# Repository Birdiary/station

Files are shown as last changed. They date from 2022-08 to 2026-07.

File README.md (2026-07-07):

# Birdiary - station
Nowadays, more species are threatened with extinction than ever before in the human era.
Especially breeding birds are considered endangered. 
At the same time, it is difficult to obtain sufficient data not only to raise awareness for this situation, but also to gain a better understanding and to develop potential countermeasures.
The Birdiary project demonstrates how a citizen science based biodiversity monitoring for birds, using an automated and easy-to-use multi-sensor feeder, can look like. 
A smart bird feeder including an environmental sensor, a microphone, as well as a balance and a camera in a wooden case which identifies the type of visiting birds using AI and publishes the recognized species, including all further collected data on an open access website. 
The station can be reproduced by anyone at an affordable price in a Do-It-Yourself format, making citizens a key contributor to biodiversity monitoring.

This repository contains the code to run the bird feeder which is equipped among other things with a camera, balance, microphone and further environmental sensors. 
All the collected data is sent to a server which is based on this [webserver](https://github.com/Birdiary/webserver). 
The repositories are currently still under development, the code for the operation of the feeder as well as for the web server are continuously updated. 
A corresponding manual for the operation of the system including open source instructions for building the feeder is available online: [Birdiary Manual](https://docs.google.com/document/d/1ItowLull5JF3irzGtbR-fCmgelG3B7DSaU1prOeQXA4/). 

Birdiary is a project which was launched by a group of students at the Institute for Geoinformatics at the University of Münster. 
If you got any questions contact us via: [info@wiediversistmeingarten.org](mailto:info@wiediversistmeingarten.org).

Any further information you can find via: [birdiary.de](https://www.wiediversistmeingarten.org/). 

## Advanced Software Development by the Community 
Citzien Scientists are driving the project substantially forward, leading to a large number of further developments. This also includes modifications to the code base. 
Some of these modifications are added directly here in the code (see [How to Contribute]([https://github.com/Birdiary/station?tab=readme-ov-file#suggest-feature](https://github.com/Birdiary/station?tab=readme-ov-file#how-to-contribute))), but some are also hosted in separate repositories. 
In the following, we list these developments. We would like to inform you that no guarantee or liability is assumed for their functionality and ask you to contact the respective operators of the repositories directly if you have any questions.  

* [Birdiary Image Raspberry Pi Zero 2 W](https://osf.io/w8gef): The available PDF describes the necessary adjustments needed to enable the Birdiary image to be used on a Raspberry Pi Zero 2 W. 
* [betzBirdiary](https://github.com/herbbetz/betzBirdiary): Modified code base that may be of interest to those using the Raspberry Pi Zero 2 W or Raspberry Pi 4 Model B as microcontroller. The repository uses the libraries Picamera2 and Pigpio (for DHT and HX711), is compatible with Bookworm (Raspian Debian 12) and includes a GUI for configuration purposes. 
* [Birdiary on ESP32](https://github.com/tnier01/BirdiaryStationESP32/): The repository details how to run a Birdiary station using ESP32, especially Seeed Studio XIAO ESP32S3 Sense.
* [Duisbird](https://duisbird.de/) Members of the Makerspace at VHS Duisburg developed their own version of the station based on ESP32S3 which is advanced compared to the other implementations, optimizing several aspects. You can find the information on the respective website: [https://duisbird.de/](https://duisbird.de/).

## How to Contribute
Thank you for considering contributing to Birdiary. Birdiary is an open source project, and we love to receive contributions from our community — you!
There are many ways to contribute, from writing tutorials or blog posts, improving the design of the station, submitting bug reports and feature requests or writing code which can be incorporated into Birdiary itself.
We use GitHub to host code, to track issues and feature requests, as well as accept pull requests.
This Repository comprises the code and issues for the station. Which means, if you want to contribute to the code running on the station, please contribute here. *Contributions in this repository do not have to stick to the code. They can also be about the hardware or design of the station.* Whereas when you want to contribute to the webserver (website), please use this repository [Webserver](https://github.com/Birdiary/webserver).

### Reporting Bugs
If you find a security vulnerability, do NOT open an issue. Email info@wiediversistmeingarten.org instead.
 
If you encounter a bug, check if the bug has already been reported as [issue](https://github.com/Birdiary/station/issues). If the bug has not been reported, you can open a [new issue](https://github.com/Birdiary/station/issues/new) to report the bug, please add the label "bug".
 
When filing an issue, make sure to answer these four questions:
> 1. Which hardware components (e.g. microcontroller, sensors) are you using?
> 2. Which software components (e.g. IDE, libraries, packages) are you using?
> 3. What did you do?
> 4. What did you expect to see?
> 5. What did you see instead?

### Suggest Feature
If you wish a special feature, feel free to add it as new [issue](https://github.com/Birdiary/station/issues/new). Here, please add the label "enhancement". We appreciate any suggestions.

### Code Contributions
Besides reporting bugs or suggesting features, we really appreciate code contributions. We suggest contributing through forking and pull-requests. A guideline how to fork a project and create a pull request can be found in the [Contribution to Projects Guidelines](https://docs.github.com/en/get-started/quickstart/contributing-to-projects). 
 
We review pull requests on a regular basis and give feedback or merge them directly into our main repository.

### Validating an Issue and Pull Requests
You can also contribute by merging a pull request into your local copy of the project and testing the changes. Add the outcome of your testing in a comment on the pull request.
Further, you can validate an issue or add additional context to an existing issue.

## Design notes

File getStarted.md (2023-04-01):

# Vorbereitung Pi 
- Installiere den Raspberry Pi Imager auf deinem lokalen Computer (Den Imager findest du hier: https://www.raspberrypi.com/software/)
- Verbinde die SD Karte, die später einmal im Raspberry Pi genutzt wird, mit deinem Computer (in der Regel kannst du die Micro SD Karte mit einem beigelegten Adapter in deinen PC stecken)
  - Da alle Daten auf der SD Karte gelöscht werden, solltest du eventuelle Daten vor den folgenden Schritten abgespeichert haben 
  - Starte den Raspberry Pi Imager und wähle dann im User Interface "Raspberry PI OS (32-BIT)" als Betriebssystem aus 
    - Wähle im User Interface des Raspberry Pi Imager, die SD Karte aus, die du eben mit deinem Computer verbunden hast 
    - Um den Prozess, der Betriebssystemübertragung zu beginnen, wähle entsprechend "SCHREIBEN" aus 
    - Bestätige, dass alle Daten auf der SD Karte gelöscht werden können 
  - Sobald die Bestätigung angezeigt wird, dass "Raspberry Pi OS (32-bit)" auf der eingelegten SD Karte gespeichert wurde, kann diese vom Computer entfernt werden und in den Raspberry Pi eingelegt werden (der Slot dafür ist auf der Unterseite des RaspberryPi, gegenüber der USB-Anschlüsse)
    - Solange das Überspielen auf die SD-Karte läuft, können schon die nächsten Schritte bis zum Stromanschluss durchgeführt werden  
- Nutze zwei der vier USB Ports am Raspberry Pi um sowohl Tastatur, als auch eine Maus an den Raspberry Pi anzuschließen 
- Nutze den Mini-HDMI Port mit der Aufschrift "HDMI0" um einen Bildschrim mit dem Raspberry Pi zu verbinden
- Optional wäre über "HDMI1" ein weiter Bildschirm verbindbar 
- Schließe das RaspberryPi Netzteil an der Buchse mit der Bezeichnung "POWER IN" an, um den Raspberry Pi mit dem Strom zu verbinden 
- Sofern dein Bildschirm eingeschaltet ist, sollte der Raspberry Pi nun starten und eine graphische Nutzerberfläche angezeigt werden, dies kann ein paar Minuten dauern. 

# initiales Starten Raspberry Pi  
- Es kann sein, dass es zu der Meldung kommt "Resized root file system. Rebooting in 5 seconds". Dann einfach abwarten und der Raspberry Pi startet selbständig erneut 
- Erscheint die Oberfläche, gilt es noch einige Einstellungen durchzuführen 
  - Zunächst können Land, Sprache und Zeitzone eingestellt werden 
  - Anschließend können Nutzername und Passwort spezifiziert werden (in der Regel 
  - Anschließend kann die Bildschirmgröße angepasst werden 
  - Dann ist es möglich, dass WiFi Network festzulegen, dies am besten gleich tun 
- Anschließend kann optional das Betriebssystem aktualisiert werden 
- Mit einem Neustart wird der Raspberry Pi dann nutzbar  

# initiales Setup Raspberry Pi 
Für die folgenden Schritte öffnest du am einfachsten dieses Repository in dem Browser (Globus Icon, oben links neben der Himbeere) deines Raspberry Pi, um die Kommandos zu kopieren. 

Zur Info: Eingaben im Terminal können getätigt werden, wenn die (grüne) Zeile `pi@raspberry: ~ $` erscheint. Dies ist auch das Zeichen für eine abgeschlossene Eingabe / Installation.

## Kamera 
- Öffne das Terminal (Shortcut: Strg + Alt + T)
- Eingabe im Terminal: `sudo raspi-config`
  - Navigation mit Pfeiltasten
  - Auswahl von: 3 Interface Options  
  - Auswahl von: I1 Legacy Camera
  - Auswahl von: Ja
  - Auswahl von: Finish  
  - Auswahl von: Ja (Reboot)

## Installation verschiedener Pakete 
- Eingabe im Terminal: `pip3 install pyyaml` (Definition der Parameter)
- Eingabe im Terminal: `pip3 install schedule` (zeitliche Wiederholung der Umweltdaten Sendung)
- Eingabe im Terminal: `pip3 install --upgrade numpy`

## Luftfeuchte und Temperatur Sensor 
- Eingabe im Terminal: `sudo pip3 install adafruit-circuitpython-dht`
- Eingabe im Terminal: `sudo apt-get install libgpiod2`

## Mikrofon 
- Eingabe im Terminal: `sudo pip3 install --upgrade adafruit-python-shell`
- Eingabe im Terminal: `wget https://raw.githubusercontent.com/adafruit/Raspberry-Pi-Installer-Scripts/master/i2smic.py`
- Eingabe im Terminal: `sudo python3 i2smic.py`
  - Bestätige 'Load on reboot' mit `y` -> Enter
- Für die vorherigen drei Schritte ist eine detaillierte Anleitung unter folgendem Link zu finden: https://learn.adafruit.com/adafruit-i2s-mems-microphone-breakout/raspberry-pi-wiring-test 
- Eingabe im Terminal: `sudo apt-get install libatlas-base-dev libportaudio2 libasound-dev`
- Eingabe im Terminal: `python3 -m pip install --user sounddevice`
  - Gegebenenfalls im Terminal bestätigen durch die Eingabe von `j` und Enter. 
- Eingabe im Terminal: `python3 -m pip install --user scipy`
- Für die vorherigen drei Schritte ist eine detaillierte Anleitung unter folgendem Link zu finden: https://github.com/Infineon/i2s-microphone/wiki/Raspberry-Pi-Audio-Processing-with-Python 
- Eingabe im Terminal: `pip3 install SoundFile`

# Hardware anschließen 

Die Belegung und Nummerierung der Pins / Ports des Raspberry Pi kann unter anderem hier nachgeguckt werden: https://www.raspberrypi-spy.co.uk/wp-content/uploads/2012/06/Raspberry-Pi-GPIO-Header-with-Photo.png 

## Kamera 
- Das breite weiße Kamerakabel an einem Ende an die Kamera anschließen und am anderen Ende an den RasperryPi (an den Anschluss der mit Kamera betitelt ist), so, dass das blaue Ende zu den USB Anschlüssen zeigt 
- Das Kabel lässt sich sowohl an Pi als auch an Kamera durch das hochziehen, der grauen Abdeckung befestigen. Dieses anschließend wieder runterdrücken um das Kabel zu fixieren 

## Luftfeuchte und Temperatursensor 
- "+" -> Port 1 (3,3 V)
- Out -> Port 36 (GPIO 16)
- "-" -> Port 9 (GND) 

## Waage 
- Kabel von der Waage (Dehnungsmessstreifen) zur Wägezelle:
  - Rot: E+ 
  - Schwarz: E-
  - Grün: A-
  - Weiß: A+
- Kabel vom Pi zur Wägezelle:
  - VCC -> Port 2 (5 V)  
  - SCK -> Port 16 (GPIO 23) 
  - DT  -> Port 11 (GPIO 17)
  - GND -> Port 6 (GND)

## Mikrofon 
- SEL -> Port 39 (GND)
- RCL -> Port 35 (GPIO 19)
- OUT -> Port 38 (GPIO 20)
- CLK -> Port 12 (GPIO 18) 
- GND -> Port 20 (GND)
- 3V  -> Port 17 (3,3 V)

# Setup Birdiary
(Je nachdem mit welchen Benutzer man sich am RaspberryPi anmeldet, können die Verzeichnisse abweichen. Solltest du dich nicht mit dem Benutzer 'pi' anmelden, musst du den Verzeichnisnamen gegen Deinen austauschen. Aus /home/pi wird dann /home/<dein Benutzer>)
- Eingabe im Terminal: `cd /home/pi/`
- Eingabe im Terminal: `git clone https://github.com/CountYourBirds/station.git` 
- Erstelle unter https://wiediversistmeingarten.org/react/createbox deine eigene Station
- Kopiere die Box-Id in die config.yaml-Datei im Ordner `/home/pi/station`
- Navigiere in den Ordner station und öffne die `config.yaml`-Datei mit geany (Rechtsclick auf die Datei -> Geany)
  - Kopiere die Box-id an die entsprechende Stelle in der Datei
  - Speichere die Datei (Shortcut: Str + S)

# Ermöglichung des Zugriffs auf den Raspberry Pi via VNC  
- Eingabe im Terminal: `sudo nano /boot/config.txt` (detaillierte Anleitung für die Veränderung der Datei hier: https://www.shellhacks.com/raspberry-pi-force-hdmi-hotplug/)
  - Navigiere mit den Pfeiltasten der Tastatur zu den den folgenden Zeilen, entferne die Rauten am Anfang der Zeilen und nimm die entsprechenden Anpassungen vor:
    - Setze den Paramter hdmi_force_hotplug auf 1: `hdmi_force_hotplug=1`  
    - Setze den Parameter hdmi_group auf 1: `hdmi_group=1`
    - Setze den Parameter hdmi_mode auf 16: `hdmi_mode=16`
  - Zum Speichern: 
    - `Strg`+ `O` 
    - `Enter`
    - `Strg`+ `X` 
- Eingabe im Terminal: `sudo raspi-config`
  - Auswahl von: 2 Display Options
  - Auswahl von: D5 VNC Resolution  
  - Auswahl von: 1920x1080
  - Auswahl von: OK
  - Auswahl von: 3 Interface Options 
  - Auswahl von: VNC 
  - Auswahl von: Ja 
  - Auswahl von: Finish
  - Auswahl von: Ja (Reboot)
- Kurz abwarten und das `Va` Icon anklicken oben rechts neben dem WLAN Zeichen 
- IP Adresse die unter Konnektivität gelistet ist auf Rechner der auf PI zugreifen soll im VNC Viewer eintragen (vorheriger Download der VNC Viewer App für entsprechendes Betriebssystem: https://www.realvnc.com/de/connect/download/viewer/) und mit dem Raspberry Pi verbinden  
- Passwort und Benutzername des pis entsprechend eintragen
- Verbindung sollte funktioneren  

# Automatische Ausführung ermöglichen 
- Eingabe im Terminal: `sudo apt-get install xterm`
  - Bestätigung mit `J` -> Enter  
- Eingabe im Terminal: `mkdir -p ~/.config/autostart`
  - (Das Terminal gibt kein Feedback bei erfolgreicher Ausführung, außer, dass eine neue Zeile und keine Fehlermeldung erscheinen)  
- Eingabe im Terminal: `nano ~/.config/autostart/lxterm-autostart.desktop`
- In der Datei einfügen: 
```
[Desktop Entry]
Encoding=UTF-8
Name=Terminal autostart
Comment=Start a terminal and list directory
Exec=/usr/bin/lxterm -e 'bash ~/station/startup.sh'
```
- `Strg`+ `O` 
- `Enter`
- Eingabe im Terminal: `sudo reboot`

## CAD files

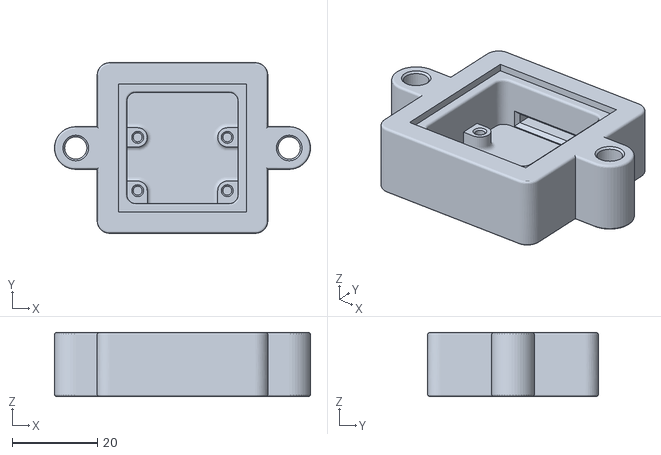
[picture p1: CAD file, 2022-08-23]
files/Cam_Support.stl
60.0 x 40.0 x 15.0

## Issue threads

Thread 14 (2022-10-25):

sensors and cables at bottom are unprotected and loose

jsten07, 2022-10-25:
Microphone and temperature / humidity sensor are hanging loose at the bottom of the station.

- Create protection with wood or 3D-printer
- At least mount sensors with screws to bottom

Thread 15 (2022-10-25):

difficult to mount station at a wall with the peaked roof

jsten07, 2022-10-25:
Peaked roof has some overhang at the back so it can not be mounted to a wall easily

- Shorten roof at the back
- Build station with pitched roof

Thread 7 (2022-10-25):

Power supply (cable) unprotected

jsten07, 2022-10-25:
Just the usual Raspberry Pi power supply is plugged into the USB-C port, so it is exposed to the elements and difficult to fasten.

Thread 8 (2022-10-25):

Enlarge room for fodder

jsten07, 2022-10-25:
Partially solved by mounting the interior wall angled

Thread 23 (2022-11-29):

"out of resources" while starting the camera

NJaku01, 2022-11-29:
With the new program I had the problem that there always was the problem "out of resources" when it tried to start the camera, since it also was sending all movements at the same time. After removing all movements to send, it worked properly again. So my solution would be not start the camera and send the data at the same time

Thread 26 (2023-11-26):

Exchange DHT22

Marwe, 2023-11-26:
We had bad experiences with the DHT22 sensor in measurement stations (values, productive life time), BME280 is our current recommended sensor (see https://sensor.community/de/sensors/airrohr/).

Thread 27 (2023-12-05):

weatherproof and stand-alone station

tnier01, 2023-12-05:
The weather protection of the station should be reconsidered. If it is not treated with linseed oil or varnish, mould can easily form.
Perhaps there are other treatment options for the wood, or other materials such as 3D printing, which would make the station more robust. Otherwise, there will be many negative experiences, which will increasingly reduce the motivation of the citizen scientists involved.

- [ ] Strengthening the weather resistance of the station

In addition, the station should be designed to operate autonomously. This includes various aspects, such as the power connection (cable, PowerBank, solar) but also the network connection (Wifi, mobile radio, LoRa)

- [ ] stand-alone station

This issue serves as a starting point for the discussion and should result in many individual aspects and issues.

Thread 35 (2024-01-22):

Assistant who guides you through the initial installation

tnier01, 2024-01-22:
There should be a wizard that guides you through the initial installation process as soon as the SD card is inserted in the Raspberry Pi. This can include the following steps:
- Setting up config.yaml (boxId, environmentTimeDeltaInMinutes, weightThreshold, calibration_weight, terminal_weight, cameraRotation, weightResetInMinutes)
- All required files downloaded
- Performed all required adjustments to the operating system.

Similar to MrBeam, it should be possible to establish a connection to the Raspberry Pi via a local network hosted by the Raspberry Pi using a website that guides you through the installation process.

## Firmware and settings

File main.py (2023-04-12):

import sys
import shutil
import time
import schedule
import numpy as np
from datetime import datetime, timedelta 
import os 
import yaml
import json
import logging
from logging.handlers import TimedRotatingFileHandler
import glob
import requests



dev_mode = False
if not dev_mode:
    import requests

if not os.path.exists('files'):
    os.makedirs('files')
if not os.path.exists('logs'):
    os.makedirs('logs')
if not os.path.exists('environments'):
    os.makedirs('environments')
if not os.path.exists('movements'):
    os.makedirs('movements')
else: 
    files = glob.glob('movements/*')
    for f in files:
        os.remove(f)
if not os.path.exists('savedMovements'):
    os.makedirs('savedMovements')
if not os.path.exists('temp'):
    os.makedirs('temp')

logname = "logs/birdiary.log"
file_handler = TimedRotatingFileHandler(logname, when="midnight", interval=1)
file_handler.suffix = "%Y%m%d"

""" # This block just works for Python version >= 3.9
logging.basicConfig(encoding='utf-8', 
                    level=logging.DEBUG, 
                    format='%(asctime)s %(levelname)s: %(message)s',
                    handlers=[
                      file_handler,
                      logging.StreamHandler(sys.stdout)
                    ]
) 
"""
logger = logging.getLogger()

logger.setLevel(logging.DEBUG)  
logger.addHandler(file_handler)
logger.addHandler(logging.StreamHandler(sys.stdout))


logging.info("Start setup!") 

# Read config.yaml file
logging.info("Reading configuration file!")
with open("config.yaml", 'r') as stream:
    yamlData = yaml.safe_load(stream)
    
# parse loglevel if present
try:  # make it backward compatible to older Versions
    loglevel = yamlData["misc"]["loglevel"]
    if loglevel == 0 or loglevel == 10 or loglevel == 20 or loglevel == 30 or loglevel == 40 or loglevel == 50:
        # referring to https://docs.python.org/3/library/logging.html#logging-levels
        logger.setLevel(loglevel)
    else:
        logger.error("Loglevel in configuration file wrong")
except:
    logger.error("loglevel in configuration not set")

# parse dev_mode if present
try:  # make it backward compatible to older Versions
    dev_mode = yamlData["misc"]["dev_mode"]
except:
    dev_mode = False
    logger.error("dev_mode in configuration not set, disabled by default")

serverUrl = yamlData["server"]["url"]
boxId = yamlData["station"]["boxId"]
environmentTimeDeltaInMinutes = yamlData["station"]["environmentTimeDeltaInMinutes"] # waiting time to send environment requests 
weightThreshold = yamlData["station"]["weightThreshold"] # weight which is the threshold to recognize a movement 
terminal_weight = yamlData["station"]["terminal_weight"] # reference unit for the balance
calibration_weight = yamlData["station"]["calibration_weight"] # reference unit for the balance
camera_rotation =  yamlData["station"]["cameraRotation"]
weightResetInMinutes = yamlData["station"]["weightResetInMinutes"]

logging.info('loglevel=' + str(loglevel))
logging.info('dev_mode=' + str(dev_mode))
logging.info('environmentTimeDeltaInMinutes=' + str(environmentTimeDeltaInMinutes))

# Setup Camera 
logging.info("Setup camera!")
import io
import random
import picamera

camera = picamera.PiCamera()
camera.rotation = camera_rotation
camera.resolution = (1280, 960)
stream = picamera.PiCameraCircularIO(camera, seconds=5)
camera.start_recording(stream, format='h264')

# Setup DHT22 (humidity + temperature) 
logging.info("Setup DHT22!")
import adafruit_dht
from board import *
SENSOR_PIN = D16 # use not board but GPIO number 
dht22 = adafruit_dht.DHT22(SENSOR_PIN, use_pulseio=False)

# Setup Balance
logging.info("Setup balance!")
EMULATE_HX711=False

if not EMULATE_HX711:
    import RPi.GPIO as GPIO
    from balance.hx711 import HX711
else:
    from balance.emulated_hx711 import HX711

hx = HX711(17, 23)

hx.set_reading_format("MSB", "MSB")
# readValueTerminal/referenceValueOnBalance=referenceUnit e.g. -1020389.3333333334/1000 = -1020,389

if calibration_weight != 0:
    balanceReferenceUnit = terminal_weight/calibration_weight
    hx.set_reference_unit(balanceReferenceUnit)

hx.power_up()
hx.reset()
time.sleep(30)
hx.tare()

# Setup Microphone 
logging.info("Setup microphone!")
from rec_unlimited import record
from multiprocessing import Process

logging.info("Setup finished!") 
 
def write_environment(environment_data):
    filename = 'environments/' + environment_data['date'] + '.json'
    with open(filename, 'w') as wfile:
        json.dump(environment_data, wfile)

def write_movement(movement_data):
    with open(data_filename, 'w') as jsonfile:
        jsonfile.write(movement_data)

# Function to send movement data to the server
def send_realtime_movement(files):
        
    if dev_mode:
        logging.warning('send_movement deactivated')
        logging.warning('received: ' + str(video_filename) + ' ' + str(audio_filename) + ' ' + str(data_filename))
    else:
        try:
            logging.debug(serverUrl + 'movement/' + boxId)
            r = requests.post(serverUrl + 'movement/' + boxId, files=files, timeout=60)
            logging.info('Following movement data send: %s', files)
            logging.debug('Corresponding movement_id: %s', r.content)
        except (requests.ConnectionError, requests.Timeout) as exception:
            logging.warning('No internet connection. ' + str(exception))
            logging.warning('Saving files to send later')
            shutil.move(audio_filename, save_audio_filename)
            shutil.move(video_filename, save_video_filename)
            write_movement(files['json'][1])
        else:
            os.remove(video_filename)
            os.remove(audio_filename)

def send_realtime_environment(environmentData):
    if dev_mode:
        logging.warning('send_environment deactivated')
        logging.warning('received: ' + str(environmentData))
    else:
        try:
            r = requests.post(serverUrl + 'environment/' + boxId, json=environmentData, timeout=20)
            logging.info('Following environment data send: %s', environmentData)
            logging.debug('Corresponding environment_id: %s', r.content)
        except (requests.ConnectionError, requests.Timeout) as exception:
            logging.warning('No internet connection. ' + str(exception))
            logging.warning("Saving environment data to send later")
            write_environment(environmentData)
        else:
            send_data()            

# Function to track a environment  
def track_environment(): 
    try:
      logging.info("Collect Environment Data") 
      environment = {}
      environment["date"] = str(datetime.now())
      environment["temperature"] = dht22.temperature
      environment["humidity"] = dht22.humidity
      
      logging.info("Environment Data: ")
      logging.info(environment)
                  
      send_realtime_environment(environment)
      
      global environmentData 
      environmentData = environment 
    except Exception as e:
      logging.error(e)  

# predefined variables 
environmentData = None
audio_filename = None
video_filename = None
save_audio_filename = None
save_video_filename = None
temp_audio_filename = 'temp/audio.wav'
data_filename = None
recorder = None

def tare():
    weight2 = hx.get_weight(15)
    if(weight2<weightThreshold):
        while((weight2 < -0.5 or weight2>0.5)):
            logging.info("Measured weight:" + str(weight2) + " not in valid range. Start taring")
            hx.tare()
            time.sleep(5)
            weight2 = hx.get_weight(15)
    logging.info("Measured weight:" + str(weight2) + " in valid range. Stop taring")
            



def set_filenames(movementStartDate):
    global save_audio_filename
    save_audio_filename = 'savedMovements/' + str(movementStartDate) + '.wav'
    global save_video_filename
    save_video_filename = 'savedMovements/' + str(movementStartDate) + '.h264'
    global audio_filename
    audio_filename = 'movements/' + str(movementStartDate) + '.wav'
    global video_filename
    video_filename = 'movements/' + str(movementStartDate) + '.h264'
    global data_filename
    data_filename = 'savedMovements/' + str(movementStartDate) + '.json'

# Function to track a movement      
def track_movement(): 
   values = []

   

   
   # schedule an environment track for every x minutes    
   schedule.every(environmentTimeDeltaInMinutes).minutes.do(track_environment)
   schedule.every(weightResetInMinutes).minutes.do(tare)



   while True:
       try:
           schedule.run_pending()
           
           weight = hx.get_weight(15)  
           
           if (weight < weightThreshold  and len(values) == 0):
              logging.info("Waiting for movement! (currently measured weight: " + str(weight) + ")")
           
           # start movement if weight higher than threshold is recognized 
           if (weight > weightThreshold and len(values) == 0):
              logging.info("Movement recognized!") 
              movementStartDate = datetime.now()
              set_filenames(movementStartDate)
              
              global recorder
              recorder = Process(target=record, args=(temp_audio_filename,))
              recorder.start()
              
              camera.wait_recording(1) # continue camera recording 
            
              values.append(weight) # add current weight to weight list 

           else: 
           # continue movement if currently recognized weight is above threshold 
              if (weight > weightThreshold):
                 values.append(weight)
                 camera.wait_recording(1)

                 logging.info("Currently measured weight: " + str(weight))

           hx.reset()          
        
           # stop movement if weight is below threshold 
           if (weight < weightThreshold):
              if (len(values) >= 1):
                 logging.info("Movement ending!") 
                 movementEndDate = datetime.now() 
                 
                 duration = (movementEndDate - movementStartDate).total_seconds()                 
                 stream.copy_to(video_filename, seconds=duration+5)
                 stream.clear()
                                                   
                 movementData = {}
                 files = {}
                 movementData["start_date"] = str(movementStartDate)
                 movementData["end_date"] = str(movementEndDate)
                 movementData["audio"] = "audioKey"
                 movementData["weight"] = np.median(values)
                 movementData["video"] = "videoKey"
                 
                 # stop audio recording and move temporary file to output directory 
                 terminate_recorder()
                 shutil.move(temp_audio_filename, audio_filename)
                 
                 files['audioKey'] = (os.path.basename(audio_filename), open(audio_filename, 'rb'))
                 files['videoKey'] = (os.path.basename(video_filename), open(video_filename, 'rb'))

                 
                 if (environmentData != None):
                    movementData["environment"] = environmentData
                 else: 
                    movementData["environment"] = {}
                 
                 logging.info("Movement Data: ")
                 logging.info(movementData)
                 
                 files["json"] = (None, json.dumps(movementData), 'application/json')

                 send_realtime_movement(files)
                 
                 values = []

                 
       except (KeyboardInterrupt, SystemExit):
           cleanAndExit()
           
def cleanAndExit():
  camera.close()
  terminate_recorder()
  sys.exit(2)
  
def terminate_recorder():
  global recorder
  if recorder is not None and recorder.is_alive():
    recorder.terminate()
    logging.info("terminated recorder")
  else:
    logging.debug("no alive recorder")
    
#Function to send environment data to the server
def send_environment(filename, server_url, box_id):
	try:
		with open(filename, 'r') as envFile:
			data = json.load(envFile)
	except:
		os.remove(filename)
		
	if dev_mode:
		logging.warning('send_environment deactivated')
		logging.warning('received: ' + str(data))
	else:
		try:
			r = requests.post(server_url + 'environment/' + box_id, json=data, timeout=20)
			logging.info('Following environment data send: %s', data)
			logging.debug('Corresponding environment_id: %s', r.content)
		except (requests.ConnectionError, requests.Timeout) as exception:
			logging.warning('No internet connection. ' + str(exception))
		else:
			os.remove(filename)
			
# Function to send movement data to the server
def send_movement(video_filename, audio_filename, data_filename, server_url, box_id):
	try: 
		with open(data_filename, 'r') as dataFile:
			data = json.load(dataFile)
		files = {}
		files['videoKey'] = (os.path.basename(video_filename), open(video_filename, 'rb'))
		files['audioKey'] = (os.path.basename(audio_filename), open(audio_filename, 'rb'))
		files['json'] = (None, json.dumps(data), 'application/json')
	except:
		os.remove(video_filename)
		os.remove(audio_filename)
		os.remove(data_filename)
		

		
	if dev_mode:
		logging.warning('send_movement deactivated')
		logging.warning('received: ' + str(video_filename) + ' ' + str(audio_filename) + ' ' + str(data_filename))
	else:
		try:
			logging.debug(serverUrl + 'movement/' + box_id)
			r = requests.post(serverUrl + 'movement/' + box_id, files=files, timeout=60)
			logging.info('Following movement data send: %s', files)
			logging.debug('Corresponding movement_id: %s', r.content)
		except (requests.ConnectionError, requests.Timeout) as exception:
			logging.warning('No internet connection. ' + str(exception))
		else:
			os.remove(video_filename)
			os.remove(audio_filename)
			os.remove(data_filename)

def send_data():
	logging.info('Sending stored data')
	environmentFiles = sorted(glob.glob('environments/*.json'))
	videoFiles = sorted(glob.glob('savedMovements/*.h264'))
	audioFiles = sorted(glob.glob('savedMovements/*.wav'))
	dataFiles = sorted(glob.glob('savedMovements/*.json'))	

	for file in environmentFiles:
		send_environment(file, serverUrl, boxId)
	for (video, audio, data) in zip(videoFiles, audioFiles, dataFiles):
		send_movement(video, audio, data, serverUrl, boxId)
	logging.info('All stored data send!')
        
logging.info("Start Birdiary!")
track_movement() 

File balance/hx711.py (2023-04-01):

#

import RPi.GPIO as GPIO
import time
import threading



class HX711:

    def __init__(self, dout, pd_sck, gain=128):
        self.PD_SCK = pd_sck

        self.DOUT = dout

        # Mutex for reading from the HX711, in case multiple threads in client
        # software try to access get values from the class at the same time.
        self.readLock = threading.Lock()
        
        GPIO.setmode(GPIO.BCM)
        GPIO.setup(self.PD_SCK, GPIO.OUT)
        GPIO.setup(self.DOUT, GPIO.IN)

        self.GAIN = 0

        # The value returned by the hx711 that corresponds to your reference
        # unit AFTER dividing by the SCALE.
        self.REFERENCE_UNIT = 1
        self.REFERENCE_UNIT_B = 1

        self.OFFSET = 1
        self.OFFSET_B = 1
        self.lastVal = int(0)

        self.DEBUG_PRINTING = False

        self.byte_format = 'MSB'
        self.bit_format = 'MSB'

        self.set_gain(gain)

        # Think about whether this is necessary.
        time.sleep(1)

        
    def convertFromTwosComplement24bit(self, inputValue):
        return -(inputValue & 0x800000) + (inputValue & 0x7fffff)

    
    def is_ready(self):
        return GPIO.input(self.DOUT) == 0

    
    def set_gain(self, gain):
        if gain == 128:
            self.GAIN = 1
        elif gain == 64:
            self.GAIN = 3
        elif gain == 32:
            self.GAIN = 2

        GPIO.output(self.PD_SCK, False)

        # Read out a set of raw bytes and throw it away.
        self.readRawBytes()

        
    def get_gain(self):
        if self.GAIN == 1:
            return 128
        if self.GAIN == 3:
            return 64
        if self.GAIN == 2:
            return 32

        # Shouldn't get here.
        return 0
        

    def readNextBit(self):
       # Clock HX711 Digital Serial Clock (PD_SCK).  DOUT will be
       # ready 1us after PD_SCK rising edge, so we sample after
       # lowering PD_SCL, when we know DOUT will be stable.
       GPIO.output(self.PD_SCK, True)
       GPIO.output(self.PD_SCK, False)
       value = GPIO.input(self.DOUT)

       # Convert Boolean to int and return it.
       return int(value)


    def readNextByte(self):
       byteValue = 0

       # Read bits and build the byte from top, or bottom, depending
       # on whether we are in MSB or LSB bit mode.
       for x in range(8):
          if self.bit_format == 'MSB':
             byteValue <<= 1
             byteValue |= self.readNextBit()
          else:
             byteValue >>= 1              
             byteValue |= self.readNextBit() * 0x80

       # Return the packed byte.
       return byteValue 
        

    def readRawBytes(self):
        # Wait for and get the Read Lock, incase another thread is already
        # driving the HX711 serial interface.
        self.readLock.acquire()

        # Wait until HX711 is ready for us to read a sample.
        while not self.is_ready():
           pass

        # Read three bytes of data from the HX711.
        firstByte  = self.readNextByte()
        secondByte = self.readNextByte()
        thirdByte  = self.readNextByte()

        # HX711 Channel and gain factor are set by number of bits read
        # after 24 data bits.
        for i in range(self.GAIN):
           # Clock a bit out of the HX711 and throw it away.
           self.readNextBit()

        # Release the Read Lock, now that we've finished driving the HX711
        # serial interface.
        self.readLock.release()           

        # Depending on how we're configured, return an orderd list of raw byte
        # values.
        if self.byte_format == 'LSB':
           return [thirdByte, secondByte, firstByte]
        else:
           return [firstByte, secondByte, thirdByte]


    def read_long(self):
        # Get a sample from the HX711 in the form of raw bytes.
        dataBytes = self.readRawBytes()


        if self.DEBUG_PRINTING:
            print(dataBytes,)
        
        # Join the raw bytes into a single 24bit 2s complement value.
        twosComplementValue = ((dataBytes[0] << 16) |
                               (dataBytes[1] << 8)  |
                               dataBytes[2])

        if self.DEBUG_PRINTING:
            print("Twos: 0x%06x" % twosComplementValue)
        
        # Convert from 24bit twos-complement to a signed value.
        signedIntValue = self.convertFromTwosComplement24bit(twosComplementValue)

        # Record the latest sample value we've read.
        self.lastVal = signedIntValue

        # Return the sample value we've read from the HX711.
        return int(signedIntValue)

    
    def read_average(self, times=3):
        # Make sure we've been asked to take a rational amount of samples.
        if times <= 0:
            raise ValueError("HX711()::read_average(): times must >= 1!!")

        # If we're only average across one value, just read it and return it.
        if times == 1:
            return self.read_long()

        # If we're averaging across a low amount of values, just take the
        # median.
        if times < 5:
            return self.read_median(times)

        # If we're taking a lot of samples, we'll collect them in a list, remove
        # the outliers, then take the mean of the remaining set.
        valueList = []

        for x in range(times):
            valueList += [self.read_long()]

        valueList.sort()

        # We'll be trimming 20% of outlier samples from top and bottom of collected set.
        trimAmount = int(len(valueList) * 0.2)

        # Trim the edge case values.
        valueList = valueList[trimAmount:-trimAmount]

        # Return the mean of remaining samples.
        return sum(valueList) / len(valueList)


    # A median-based read method, might help when getting random value spikes
    # for unknown or CPU-related reasons
    def read_median(self, times=3):
       if times <= 0:
          raise ValueError("HX711::read_median(): times must be greater than zero!")
      
       # If times == 1, just return a single reading.
       if times == 1:
          return self.read_long()

       valueList = []

       for x in range(times):
          valueList += [self.read_long()]

       valueList.sort()

       # If times is odd we can just take the centre value.
       if (times & 0x1) == 0x1:
          return valueList[len(valueList) // 2]
       else:
          # If times is even we have to take the arithmetic mean of
          # the two middle values.
          midpoint = len(valueList) / 2
          return sum(valueList[midpoint:midpoint+2]) / 2.0


    # Compatibility function, uses channel A version
    def get_value(self, times=3):
        return self.get_value_A(times)


    def get_value_A(self, times=3):
        return self.read_median(times) - self.get_offset_A()
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

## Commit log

2022-05-03 changed to logging from print
2022-05-11 reworked arguments of rec_unlimited and improved writing files to disk
    [main.py, rec_unlimited.py]
2022-11-01 removed Cam_Support.stl
    [Cam_Support.stl]
2022-11-14 keep cam_support.stl file in repo
    [Cam_Support.stl]
2022-12-05 add camera rotation to config.yml
2022-12-06 Bug Fixes for realtime sending
    [main.py]
2023-04-01 Change /home/pi to /home/<anyuser> / Improved get_pi_Requirements (#18)
    * Create log
    * Delete log
    * Changed hard codes pathes to /home/pi/station and replaced it with ~/station.
    This makes it possible to run the Script under anothers users home.
    * Changed set_gain from <variable> is <value> -> <variable> == <value>
    on first Start of the script it will produce errors.
    * reworked a lot in the script to make it more Informational for users.
    I added a routine that everytime the new packages are downloaded and upgraded. This makes sure that the other compilations are based on the actual packages and Kernel sources.
    Also, some dependencies for the compilation for scipy module where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
    [hx711.py, rec_unlimited.py]
2023-04-12 add error handling for corrupted json files
    [main.py]
